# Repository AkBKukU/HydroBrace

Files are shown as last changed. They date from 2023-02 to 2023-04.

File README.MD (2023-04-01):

# Hydro Thunder CAD Replacement and Support Components  
  
## Hydro Thunder Dashboard Brace

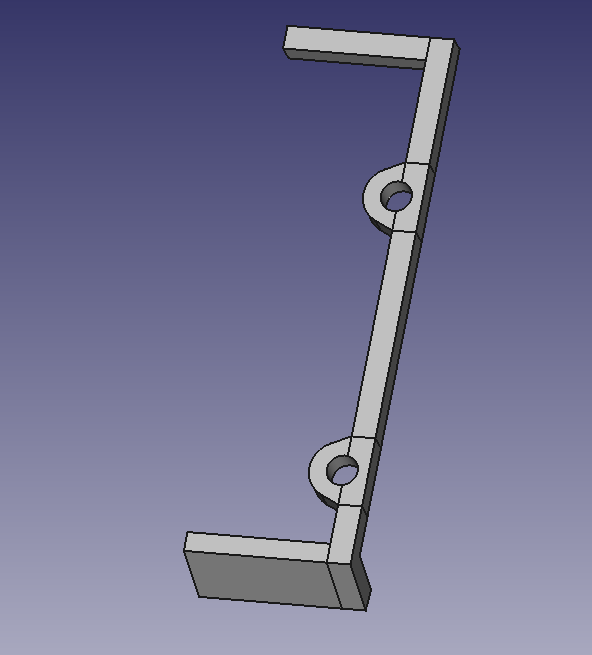
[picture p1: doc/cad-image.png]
A 3d render of the part A render of the bracket model


This is a 3D printable part to clamp down on the dashboard to reinforce the frequently broken plastic that secures it to the metal base. The parts are printed with one as modeled and the other mirrored from the original. The are installed with the original bolts over the plastic dashboard.

Adding foam to the bottom of the parts before putting them on may make them work even better as it will increase friction by fitting into the textured surface more.

## Sheet Metal Version

A sheet metal bend version is also available. You will need to add it twice to your cart with one being bent up and the other down.

**[CRS Mild Steel 0.119" (3mm)](https://sendcutsend.com/materials/mild-steel/):**  
 - K-Factor: `0.38`  
 - Bend Radius: `1.6002 mm`  
 - Thickness: `3.0226 mm`

Bend Values(Per SendCutSend order) - Left side:  
 - **1**: 80 - Up  

Bend Values(Per SendCutSend order) - RIght side:  
 - **1**: 80 - Down  

After you order parts and go to install them, I highly recommend adding felt or foam to the inside part of the metal that contacts the plastic to both add friction and apply the force more evenly when clamping.

## Hydro Thunder Throttle Mount Plate

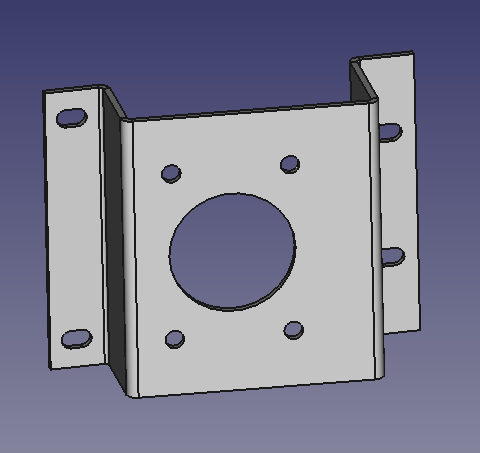
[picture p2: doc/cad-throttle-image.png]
A 3d render of the throttle mount plate A render of the mount model


The intermediate mounting bracket to attach the throttle to the control panel is prone to tearing. The file `HydroThrottleplate-Unfold.dxf` is a replacement design for this made in a thicker piece of steel to both repair and prevent future damage. The design file is designed against material of the follow parameters availble at [sendcutsend.com](https://sendcutsend.com)  
  
**[CRS Mild Steel 0.119" (3mm)](https://sendcutsend.com/materials/mild-steel/):**  
 - K-Factor: `0.38`  
 - Bend Radius: `1.6002 mm`  
 - Thickness: `3.0226 mm`

Bend Values(Per SendCutSend order):  
 - **1** (Tall side mount tab): 90 - Up  
 - **2** (Tall side inner): 94.1596 - Down  
 - **3** (Short side inner): 85.8404 - Down
 - **4** (Short side mount tab): 90 - Up  

If you want to change the material type you will need to modify the FreeCAD design file which uses the [SheetMetal Workbench](https://wiki.freecad.org/SheetMetal_Workbench) plugin. The K-factor is set on the unfolding of an object, material thickness and bend radius are set for the plugin on the base level object but for this project are referenced from a spreadsheet to make adjustments easier.

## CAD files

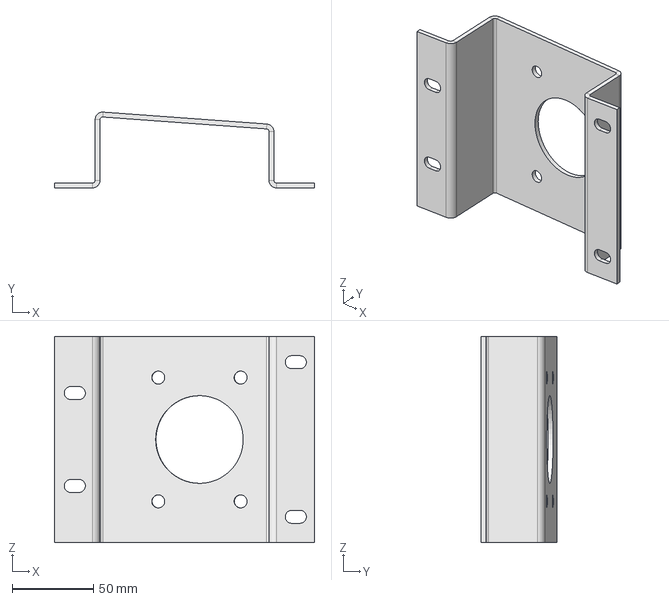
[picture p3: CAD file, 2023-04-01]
HydroThrottleplate.FCStd
160.0 x 46.6 x 127.0 mm

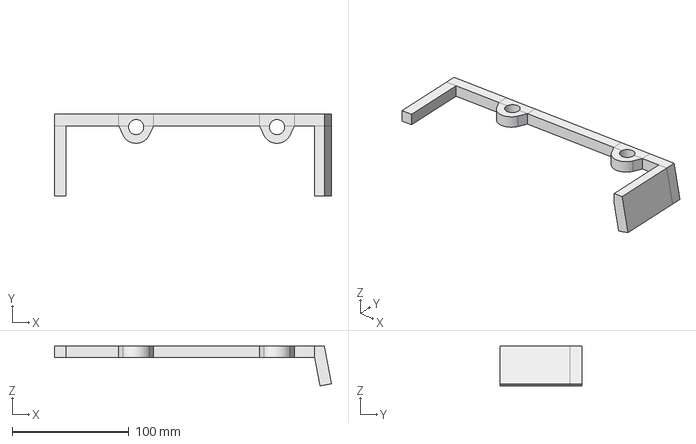
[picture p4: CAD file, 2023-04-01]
HydroBrace.FCStd
237.4 x 70.0 x 34.2 mm

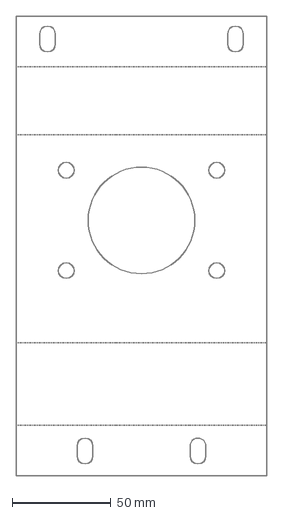
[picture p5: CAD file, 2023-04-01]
HydroThrottleplate-Unfold.dxf
127.0 x 232.6 mm

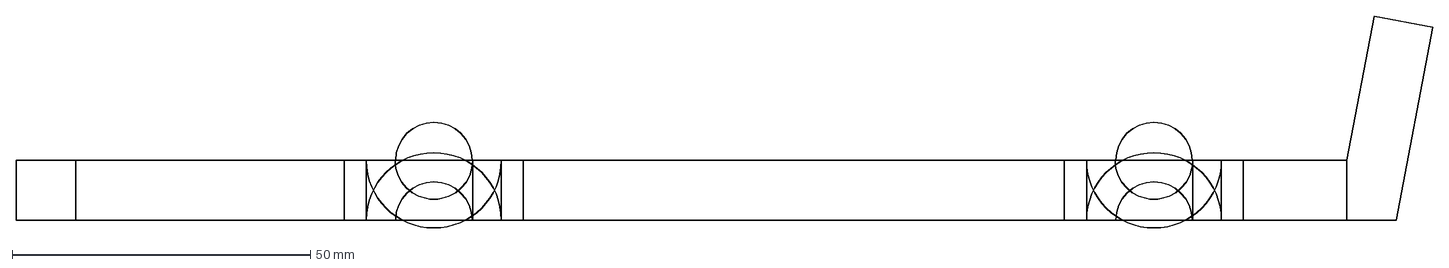
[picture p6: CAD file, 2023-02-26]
HydroBrace-Body-Side.dxf
237.4 x 35.5 mm

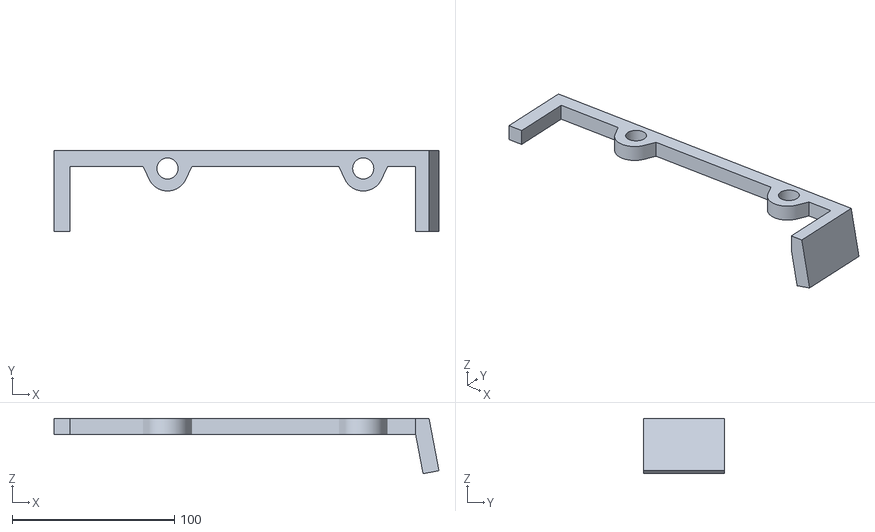
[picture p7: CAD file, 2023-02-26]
HydroBrace-Body.stl
237.4 x 50.0 x 34.2

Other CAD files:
HydroBrace-Bend.FCStd
HydroBrace-Bend.dxf
HydroBrace-Body.dxf

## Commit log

2023-02-24 basic shape
    [HydroBrace.FCStd]
2023-02-25 first revision
    renamed sketches and parts
    set sketch supporting geometry to base planes to avoid naming convention bug
    split end tabs into two separate features
    worked on spreadsheet feature - parsing error may have been due to space in name field when calling it from constraint setting window. inconsistent reproduction.
    work on bolt tab geometry
    -bolt holes and counterbores on different sketch from tabs
    -refactored reference: tab location definitions moved from tab left edge to tab centerlines. Changing the widths of the tabs would have made the holes move.
    [HydroBrace2.FCStd]
2023-02-25 Add files via upload
    hydrobrace2a.FCStd
    fixed underconstrained brace short end sketch
    hydrobrace2.FCStd
    -bolt holes and counterbores on different sketch from tabs -refactored reference: tab location definitions moved from tab left edge to tab centerlines. Changing the widths of the tabs would have made the holes move.
    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
    [HydroBrace2a.FCStd]
2023-02-26 refactor to new files
    [HydroBrace.FCStd, HydroBrace2.FCStd, HydroBrace2a.FCStd]
2023-02-26 short brace thickness refrenced
    [HydroBrace.FCStd]
2023-02-26 Print checked dimenssions and model export
    [HydroBrace-Body.dxf, HydroBrace-Body.stl, HydroBrace.FCStd]
2023-02-26 Final checked dimenssions
    [HydroBrace-Body.dxf, HydroBrace-Body.stl, HydroBrace.FCStd]
2023-02-26 Documentation started
    [HydroBrace-Body-Side.dxf]
2023-03-05 Create throttle mount plate adapter thing
    [HydroThrottleplate-Unfold.dxf, HydroThrottleplate.FCStd]
2023-03-05 Add throttle image
2023-03-05 Fix SCS URL
    [HydroBrace.FCStd]
2023-03-05 Add material link for plate
2023-03-11 Add sheet metal version of the dashboard bracket
    [HydroBrace-Bend.FCStd, HydroBrace-Bend.dxf, HydroBrace.FCStd]
2023-03-20 Added bend angle and direction information for ordering from Send Cut Send
2023-04-01 Adjustments made after ordering parts
    [HydroBrace-Bend.dxf, HydroBrace.FCStd, HydroThrottleplate-Unfold.dxf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]
